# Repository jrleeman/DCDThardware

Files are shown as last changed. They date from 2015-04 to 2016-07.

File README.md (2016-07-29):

# DCDT Brackets and Accessories

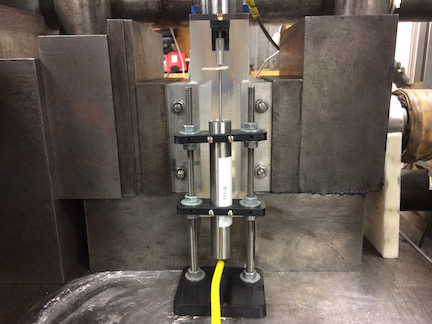
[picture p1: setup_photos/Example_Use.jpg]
Setup Photo


Direct Current Displacement Transducers (DCDTs) are a great way to measure the
linear position of an object. Designing brackets to hold DCDTs and their cores are one of the more
time consuming tasks with their implementation. Here I have collected a group of objects to
help utilize DCDTs in a variety of measurement situations. Each subfolder has projects in that
category, each project has the OpenSCAD files, STL files, photos, and a README with
a description and instructions.

## DCDT Holders
Brackets to hold the body of a DCDT, either mounted to a fixed reference, custom surface, or to the body in motion.

* [Magnetic DCDT Holder and Base](DCDT_Holders/Magnetic_DCDT_Holder)
* [Slotted Rail DCDT Holder](DCDT_Holders/Screw_Rail_DCDT_Holder)

## DCDT Core Mounts
Holding the core of a DCDT parallel to the motion and firm is a crucial task. These brackets provide a way to mount cores to various surfaces and systems.

* [Glue on Arms (long and short)](DCDT_Core_Mounts/glue_on_arms)
* [Sliding holder for cores](DCDT_Core_Mounts/sliding_core_holder)

## Accessories  
Useful accessories for DCDT operation and parts storage.

* [Core Labels](Accessories/core_label)
* ["L" Brackets for Rails](Accessories/rail_L_brackets)
* ["U" Brackets for Rails](Accessories/rail_U_brackets)

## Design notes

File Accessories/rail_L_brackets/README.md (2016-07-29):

# Rail "L" Brackets

Brackets to allow mounting of the rails to surfaces with glue or screws.

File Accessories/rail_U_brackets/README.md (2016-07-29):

# Rail "U" Brackets

Brackets to allow mounting of the rails to surfaces with glue or screws.

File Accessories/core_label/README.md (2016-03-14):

# DCDT Core Labels

Easily label cores to prevent mix-ups that could result in changed calibration
factors and other problems! Designed for 2-56 threaded core.

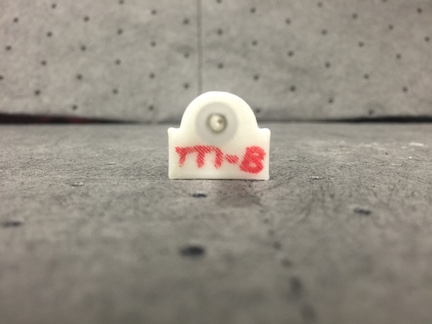
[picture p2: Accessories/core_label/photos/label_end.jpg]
Core label on DCDT


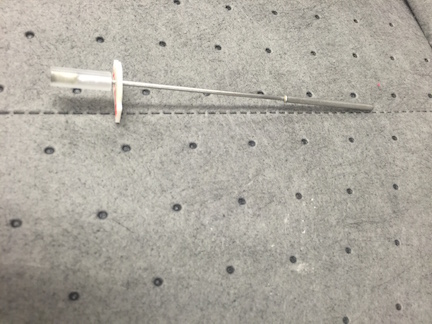
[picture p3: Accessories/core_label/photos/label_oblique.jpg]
Core label on DCDT


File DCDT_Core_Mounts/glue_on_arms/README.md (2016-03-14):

# Glue on Core Holders

These brackets will allow mounting of the core to a perpendicular surface.
Most easily affixed with glue or epoxy, but could also be mounted with
a screw.

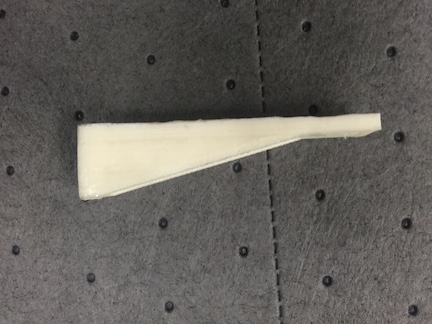
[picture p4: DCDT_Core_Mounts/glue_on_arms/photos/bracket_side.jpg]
Side view


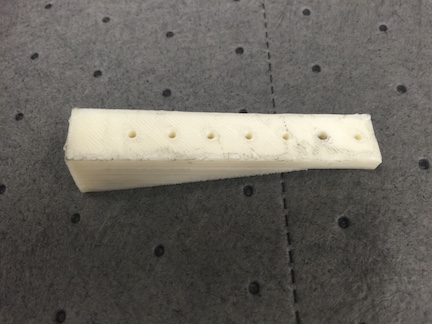
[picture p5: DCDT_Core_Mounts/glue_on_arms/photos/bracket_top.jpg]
Top view


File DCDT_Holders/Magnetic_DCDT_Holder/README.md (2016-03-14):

# Magnetic DCDT Holder and Accessories

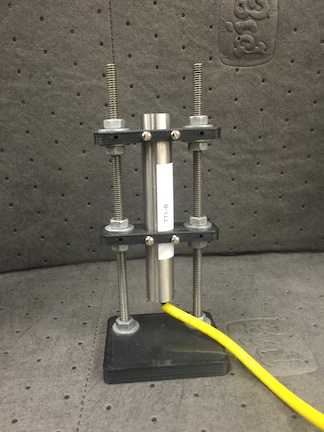
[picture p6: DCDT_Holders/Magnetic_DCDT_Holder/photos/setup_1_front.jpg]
Setup Photo


Direct Current Displacement Transducers (DCDTs) are a great way to measure the
linear position of an object. Often times affixing the DCDT to the test subject
can be problematic though. This repository contains a versatile magnetic DCDT
holder that is easily adjusted and re-mixed to suit your application. As-is the
design supports 0.75" diameter transducers, a very common size. The repository
also contains brackets for labeling DCDT cores (essential to keep calibrations
from getting mixed) and mounts for the DCDT cores to a perpendicular surface. See the photos folder for many pictures and examples of use!

## Required Materials
- (1) 3D printed base
- (2+) 3D printed DCDT mounting brackets
- (2) 1/4" all-thread rod cut to desired mounting system height
- (12) 1/4" nuts
- (10) 1/4" washers
- (3) N48 Neodymium Magnets ([Can be purchased from Amazon](http://amzn.com/B001KV38ES))
- Super Glue
- 4-40 tap
- (4) 4-40 x 1" screws

## Assembly

- Trim the rafting legs off of each part and sand smooth.
- Tap the DCDT mounting holes in the DCDT brackets with the 4-40 tap and insert the screws.
- Insert 1/4" nuts into the bottom of the base bracket. Secure with a small amount of glue.
- Place a couple drops of glue into each magnet well in the base. Insert the magnets.
- Screw one nut about 1" onto each all-thread rod. Place a washer.
- Screw the all-thread rods into the base. Tighten the top nut lightly to secure the rods.
- Screw a nut and washer combination onto each all-thread rod.
- Place a DCDT bracket onto the all-thread rods.
- Add another nut/washer combination and secure the DCDT bracket in-place where desired.
- Screw a nut and washer combination onto each all-thread rod.
- Place a DCDT bracket onto the all-thread rods.
- Add another nut/washer combination and secure the DCDT bracket in-place where desired.
- Repeat if necessary for more brackets.
- Affix the DCDT.
- Have a beverage.

## Photos
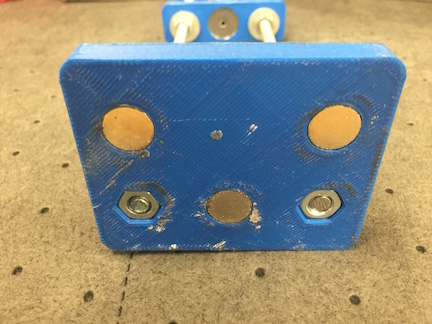
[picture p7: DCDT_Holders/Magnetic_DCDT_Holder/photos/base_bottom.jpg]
Bottom of the base

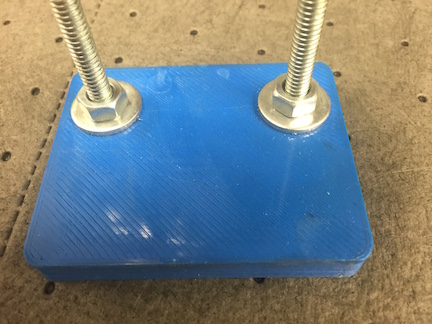
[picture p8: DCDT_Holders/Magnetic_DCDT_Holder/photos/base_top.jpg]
Top of the base

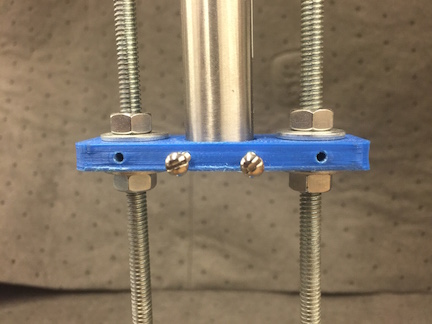
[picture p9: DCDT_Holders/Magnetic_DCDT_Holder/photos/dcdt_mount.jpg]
DCDT Mount

Example Setup
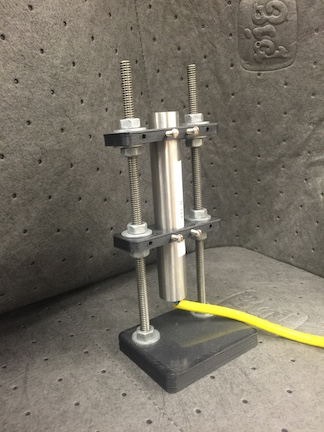
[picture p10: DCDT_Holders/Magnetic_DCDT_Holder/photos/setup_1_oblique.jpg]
Example Setup

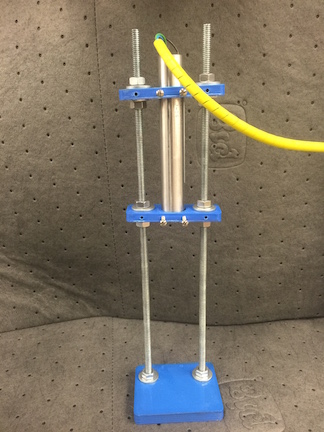
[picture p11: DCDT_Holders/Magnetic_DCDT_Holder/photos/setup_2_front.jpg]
Example Setup

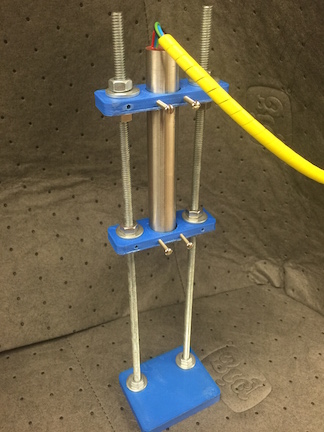
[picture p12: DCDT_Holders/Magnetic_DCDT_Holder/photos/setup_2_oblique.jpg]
Example Setup


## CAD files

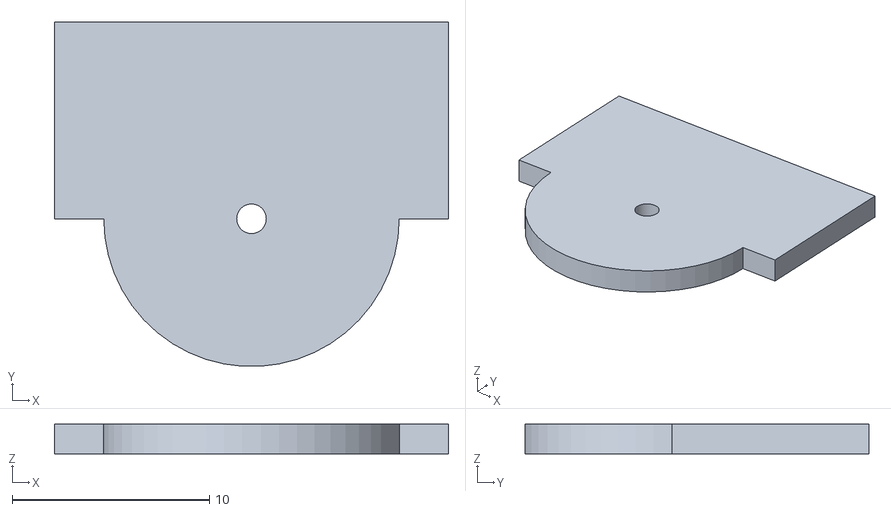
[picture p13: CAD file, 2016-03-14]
Accessories/core_label/stl/DCDT_Core_Label.stl
20.0 x 17.5 x 1.50

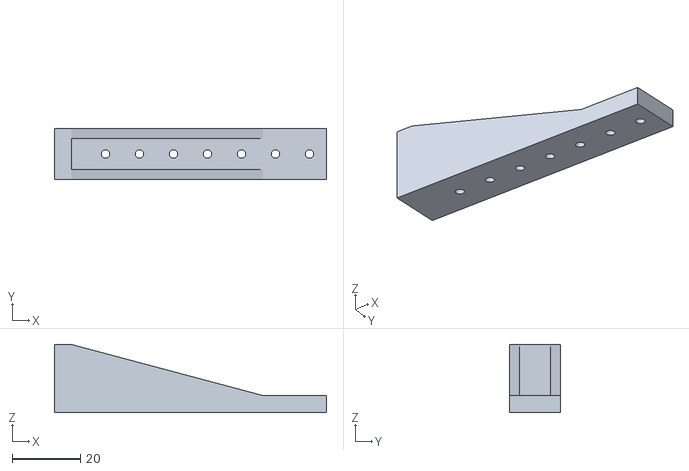
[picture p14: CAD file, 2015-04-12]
DCDT_Core_Mounts/glue_on_arms/stl/DCDT_Center_Block_Bracket_Long.stl
80.0 x 15.0 x 20.0

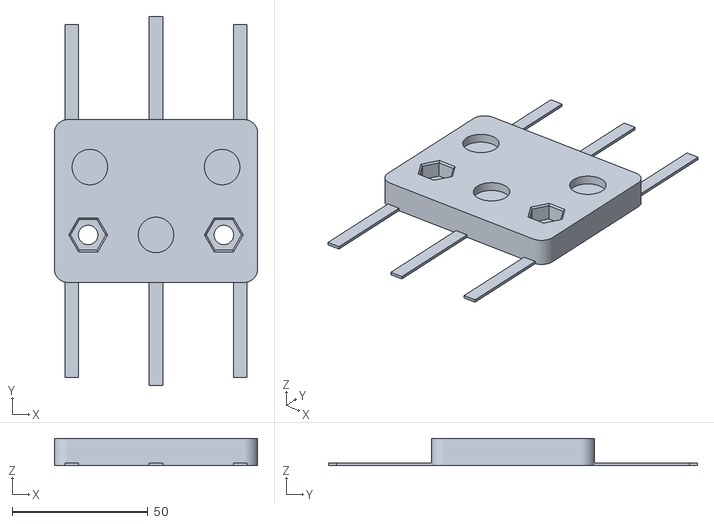
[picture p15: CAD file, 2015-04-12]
DCDT_Holders/Magnetic_DCDT_Holder/stl/DCDT_Base.stl
75.0 x 136.0 x 10.0

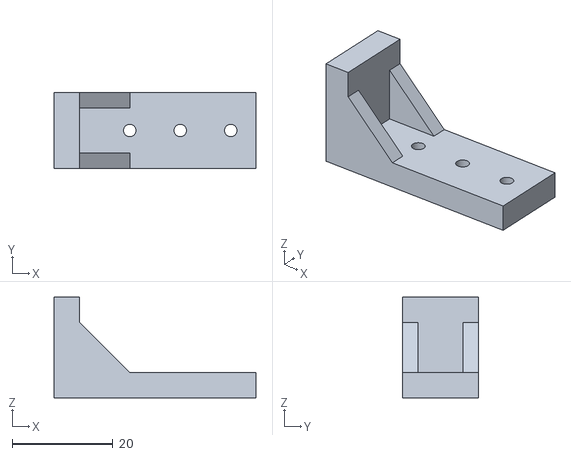
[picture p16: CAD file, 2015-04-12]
DCDT_Core_Mounts/glue_on_arms/stl/DCDT_Center_Block_Bracket.stl
40.0 x 15.0 x 20.0

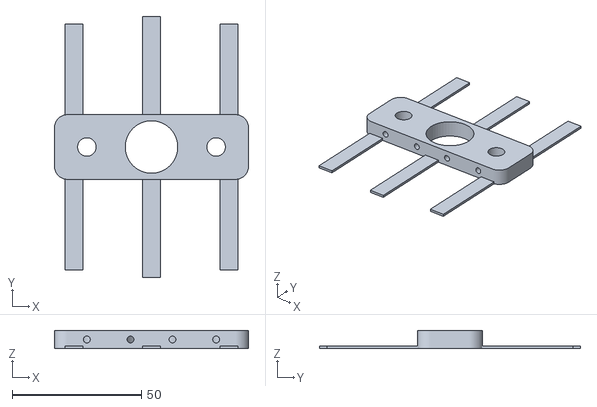
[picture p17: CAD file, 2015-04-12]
DCDT_Holders/Magnetic_DCDT_Holder/stl/DCDT_Bracket.stl
75.0 x 101.0 x 7.00

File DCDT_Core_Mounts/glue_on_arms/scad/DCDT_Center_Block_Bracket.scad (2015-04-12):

// Resolution
$fn=50;

// Base of stand
// Note, remote the radius from the dimensions
// of th rectangular base
base_width = 15;
base_thickness = 5;
base_length = 40;

// Screw Holes
screw_radius = 1.1310 + 0.1; 

difference(){
cube([base_length,base_width,base_thickness]);

translate([35,0.5*base_width,0]) cylinder(1.5*base_thickness,screw_radius,screw_radius);
translate([25,0.5*base_width,0]) cylinder(1.5*base_thickness,screw_radius,screw_radius);
translate([15,0.5*base_width,0]) cylinder(1.5*base_thickness,screw_radius,screw_radius);
}

translate([5,0,0])rotate([0,-90,0]) cube([20,15,5]);

translate([5,0,0])rotate([-90,-90,0]) linear_extrude(3) polygon(points=[[0,0],[15,0],[0,15],[0,0]],paths=[[0,1,2,3]]);

translate([5,12,0]) rotate([-90,-90,0]) linear_extrude(3) polygon(points=[[0,0],[15,0],[0,15],[0,0]],paths=[[0,1,2,3]]);

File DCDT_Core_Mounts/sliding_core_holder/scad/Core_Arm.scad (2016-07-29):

// Resolution
$fn=50;

// DCDT
dcdt_radius = 9.75;
dcdt_center_offset = 2; // How far off center is the DCDT (wall thickness of mount)

// Groove for captive nut
nut_groove_width = 4.4; // Was 4.2
nut_groove_height = 1.7;
nut_groove_off_bottom = 3;

// m3 hardware
m3_clear = 3.8/2; // Standard Fit
nut_driver_clearance = 7.9/2; // Radius of clearance for m3 nut driver
cap_head_clearance = 3.;
cap_head_depth_clearance = 3.5;

// Arm parameters
arm_length = 70;
wall_thickness = 2;
arm_width = dcdt_radius + dcdt_center_offset + nut_groove_width/2 + wall_thickness;
arm_height = nut_driver_clearance*2*2;

// Groove for threaded rod
rod_groove_width = 2.4; 
rod_groove_depth = arm_height - wall_thickness;

// Alignment arm
alignment_thickness = 2;
alignment_width = 8;

// Rail
rail_width = 10;

// Clearance notch for other rails
notch_offset = rail_width * 1.2;
notch_depth = 2;

// Uncomment for printing orientation
//rotate([0,-90,0])

difference(){
    
    union(){
        // Main body
        cube([arm_length,arm_width,arm_height]);
        
        // Alignment arm
        translate([-alignment_thickness, -alignment_width, 0])
        cube([alignment_thickness, alignment_width+arm_width, arm_height]);
    }
    
    // Notch for rail clearance
    translate([notch_offset,0,0])
    cube([arm_length,notch_depth,arm_height]);
    
    // Groove for nut
    translate([rail_width/2+m3_clear+wall_thickness,-nut_groove_width/2+dcdt_radius+dcdt_center_offset, nut_groove_off_bottom])
    cube([arm_length,nut_groove_width,nut_groove_height]);
    
    // All thread groove
    translate([rail_width/2+m3_clear+wall_thickness,-rod_groove_width/2+dcdt_radius+dcdt_center_offset,0])
    cube([arm_length, rod_groove_width, rod_groove_depth]);
    
    // Holes for M3 Mounting Screws
    translate([rail_width/2,arm_width,m3_clear+wall_thickness]) 
    rotate([90,0,0])
    cylinder(arm_width,m3_clear,m3_clear);
    
    translate([rail_width/2,arm_width,arm_height-m3_clear-wall_thickness]) 
    rotate([90,0,0])
    cylinder(arm_width,m3_clear,m3_clear);    
}

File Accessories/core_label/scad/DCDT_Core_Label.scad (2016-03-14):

// Resolution
$fn=50;

// Sizes of parts
2_56_radius = 0.75;
flag_width = 20;
flag_height = 10;
disc_radius = 7.5;
part_thickness = 1.5;

difference(){
	union(){
		cylinder(part_thickness,disc_radius,disc_radius);
		translate([flag_width/-2,0,0]) cube([flag_width,flag_height,part_thickness]);
	}

	cylinder(part_thickness*2,2_56_radius,2_56_radius);
}

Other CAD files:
DCDT_Core_Mounts/glue_on_arms/scad/DCDT_Center_Block_Bracket_Long.scad
Accessories/makerbeam_joiner/scad/beam_joiner.scad
Accessories/rail_L_brackets/scad/L_bracket_10mm_rail.scad
Accessories/rail_U_brackets/scad/U_bracket_10mm_rail.scad
DCDT_Holders/Magnetic_DCDT_Holder/scad/DCDT_Base.scad
DCDT_Holders/Magnetic_DCDT_Holder/scad/DCDT_Bracket.scad
DCDT_Holders/Screw_Rail_DCDT_Holder/scad/DCDT_Rail_Mount.scad

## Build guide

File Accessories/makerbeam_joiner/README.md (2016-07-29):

# Makerbeam Joiner

Bracket to join pieces of makerbeam with a given offset.

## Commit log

2014-08-22 Increase resolution for printing
    [DCDT_Base.scad, DCDT_Bracket.scad]
2014-08-24 Add rafts and thicken
    [DCDT_Base.scad, DCDT_Bracket.scad]
2014-08-25 Modify hole sizes
    [DCDT_Bracket.scad]
2014-08-25 Change base to use 1/4-20 all thread for risers and add nut retainers
    [DCDT_Base.scad, DCDT_Bracket.scad]
2015-04-12 Move files around for better organization
    [DCDT_Base.scad, DCDT_Base.stl, DCDT_Bracket.scad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]
2015-04-12 Move scad files
    [DCDT_Base.scad, DCDT_Bracket.scad]
2016-03-14 Reorganize structure
    [DCDT_Base.scad, DCDT_Base.stl, DCDT_Bracket.scad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]
2016-03-14 Rough design of across DDS hardware
    [Core_Arm.scad, DCDT_Rail_Mount.scad]
2016-03-15 Add U brackets for rail
    [U_bracket_10mm_rail.scad]
2016-03-15 Add L backets for rails
    [L_bracket_10mm_rail.scad]
2016-03-15 Increse hole clearances on mounting bracket
    [DCDT_Rail_Mount.scad]
2016-03-15 Make nut cut out fit 2-56 nut
    [Core_Arm.scad]
2016-03-15 Fix error in hole position calculation
    [U_bracket_10mm_rail.scad]
2016-03-23 Decrease size of DCDT hole, add center rail mounting points, and enlarge holes for M3 melt-in thread inserts
    [DCDT_Rail_Mount.scad]
2016-03-23 Decrease nut retention groove size, increase spacing for nut driver clearance.
    [Core_Arm.scad]
2016-03-23 Add tab on bracket to make alignment easier
    [Core_Arm.scad]
2016-03-23 Increase hole size for better clear fit
    [L_bracket_10mm_rail.scad, U_bracket_10mm_rail.scad]
2016-07-29 Final changes to setup after alpha testing
    [Core_Arm.scad, DCDT_Rail_Mount.scad]
2016-07-29 Add joiner block for two segments of makerbeam
    [beam_joiner.scad]
